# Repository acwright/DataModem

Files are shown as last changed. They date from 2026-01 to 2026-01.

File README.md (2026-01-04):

DataModem
=========

Data (RS-232/Serial) to Audio Modem

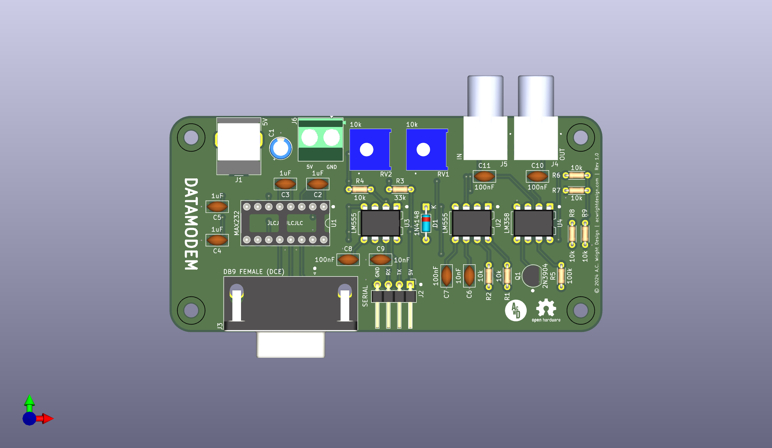
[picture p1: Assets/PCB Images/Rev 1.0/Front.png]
DataModem


Usage
-----

Connect the DataModem to your computer's serial port (or USB-to-Serial adapter) and to an audio input/output device (like a cassette recorder or audio interface). Use terminal software to send and receive data through the modem.

Configuration
--------------

- **Baud Rate**: 300 baud (recommended for best reliability)
- **Tone Frequency**: Approximately 4kHz
- **RV1**: Adjusts output signal strength to the cassette recorder
- **RV2**: Adjusts the triggering sensitivity of the Schmitt trigger for playback

How It Works
------------

The DataModem uses a simple one-tone encoding system where the presence of a tone represents a 1 bit and silence represents a 0 bit.

**Recording Data**: When transmitting, a 555 timer (U2) generates a ~4kHz square wave tone when the UART input is high. The tone is buffered and AC-coupled before being fed to the cassette recorder input. When the UART input is low, the 555 is disabled and produces no tone.

**Playing Back Data**: During playback, a Schmitt trigger detects the presence of the recorded tone. A retriggerable 555 monostable circuit (U3) converts the rapid tone pulses into a steady output signal. The monostable stays on for 300μs when triggered, and continuous triggers from the 4kHz tone keep it active, producing a clean digital output that matches the original UART signal.

The circuit is designed for 300 baud operation, providing excellent reliability with minimal bit loss when properly calibrated.

Licence
-------

This project is licensed under the CERN Open Hardware Licence Version 2 - Permissive License - see the [LICENSE](LICENSE) file for details.

Credits
-------

This project is inspired by and based on the following works:

- [Datacorder](https://www.mitchelectronics.co.uk/documents/DATACORD.pdf) by Mitchell Electronics
- [UART Cassette Tape Interface](https://maker.pro/pcb/projects/make-uart-cassette-tape-interface) by Robin Mitchell

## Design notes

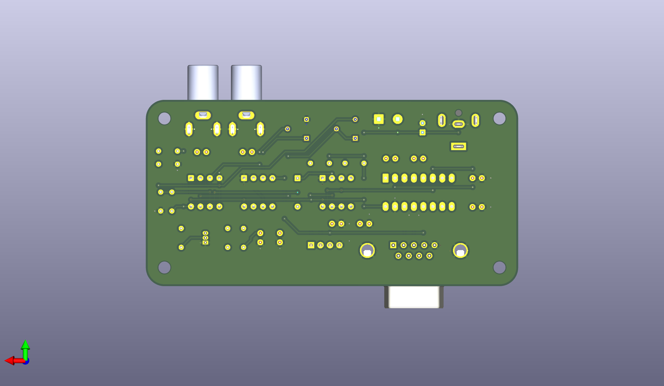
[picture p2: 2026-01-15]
Assets/PCB Images/Rev 1.0/Back.png

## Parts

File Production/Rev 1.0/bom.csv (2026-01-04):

Designator | Footprint | Quantity | Value | LCSC Part #
C1 | CP_Radial_D5.0mm_P2.50mm | 1 | 10uF
C10, C11, C7, C8 | C_Disc_D5.0mm_W2.5mm_P2.50mm | 4 | 100nF
C2, C3, C4, C5 | C_Disc_D5.0mm_W2.5mm_P2.50mm | 4 | 1uF | C28323
C6, C9 | C_Disc_D5.0mm_W2.5mm_P2.50mm | 2 | 10nF
D1 | D_DO-35_SOD27_P7.62mm_Horizontal | 1 | 1N4148
J1 | BarrelJack_CUI_PJ-063AH_Horizontal | 1 | 5V
J2 | PinHeader_1x04_P2.54mm_Horizontal | 1 | SERIAL
J4 | SWITCHCRAFT_PJRAN1X1U02X | 1 | OUT
J5 | SWITCHCRAFT_PJRAN1X1U02X | 1 | IN
J6 | TerminalBlock_Phoenix_MKDS-1,5-2-5.08_1x02_P5.08mm_Horizontal | 1 | 5V
Q1 | TO-92_Inline | 1 | 2N3904
R1, R2, R4, R6, R7, R8, R9 | R_Axial_DIN0204_L3.6mm_D1.6mm_P5.08mm_Horizontal | 7 | 10k
R3 | R_Axial_DIN0204_L3.6mm_D1.6mm_P5.08mm_Horizontal | 1 | 33k
R5 | R_Axial_DIN0204_L3.6mm_D1.6mm_P5.08mm_Horizontal | 1 | 100k
RV1, RV2 | 3386F-1-103LF | 2 | 10k
U1 | DIP-16_W7.62mm_Socket_LongPads | 1 | MAX232 | C59824
U2, U3 | DIP-8_W7.62mm | 2 | LM555
U4 | DIP-8_W7.62mm | 1 | LM358

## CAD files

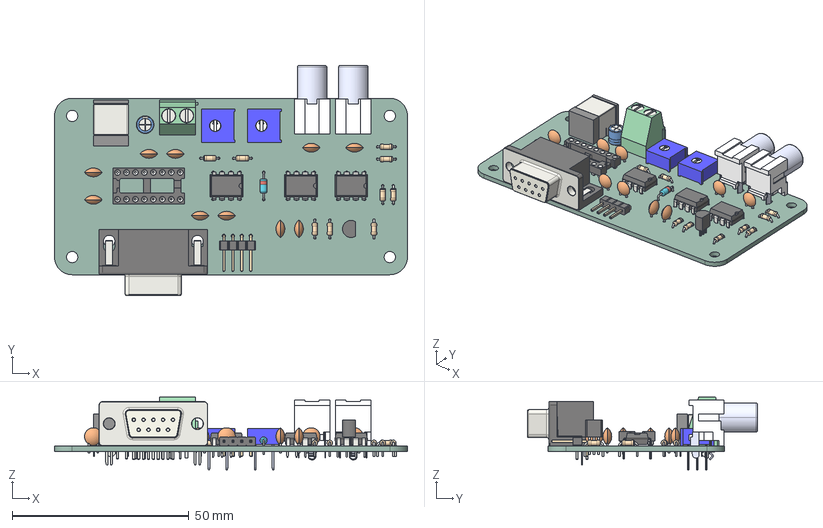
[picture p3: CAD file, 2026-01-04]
Assets/PCB Models/Rev 1.0/DataModem.step
100.0 x 65.3 x 20.7 mm
C_Disc_D5.0mm_W2.5mm_P2.50mm x 10
3386F-1-103LF x 2
DSUB-9_Socket_Horizontal_P2.77x2.84mm_EdgePinOffset7.70mm_Housed_ MountingHolesOffset9.12mm
CP_Radial_D5.0mm_P2.50mm
R_Axial_DIN0204_L3.6mm_D1.6mm_P5.08mm_Horizontal x 9
D_DO-35_SOD27_P7.62mm_Horizontal
TerminalBlock_Phoenix_MKDS-1,5-2-5.08_1x02_P5.08mm_Horizontal
BarrelJack_CUI_PJ-063AH_Horizontal
PJRAN1X1U04X-edit x 2
DIP-8_W7.62mm x 3
PinHeader_1x04_P2.54mm_Horizontal
TO-92_Inline
DIP-16_W7.62mm_Socket
DataModem_PCB

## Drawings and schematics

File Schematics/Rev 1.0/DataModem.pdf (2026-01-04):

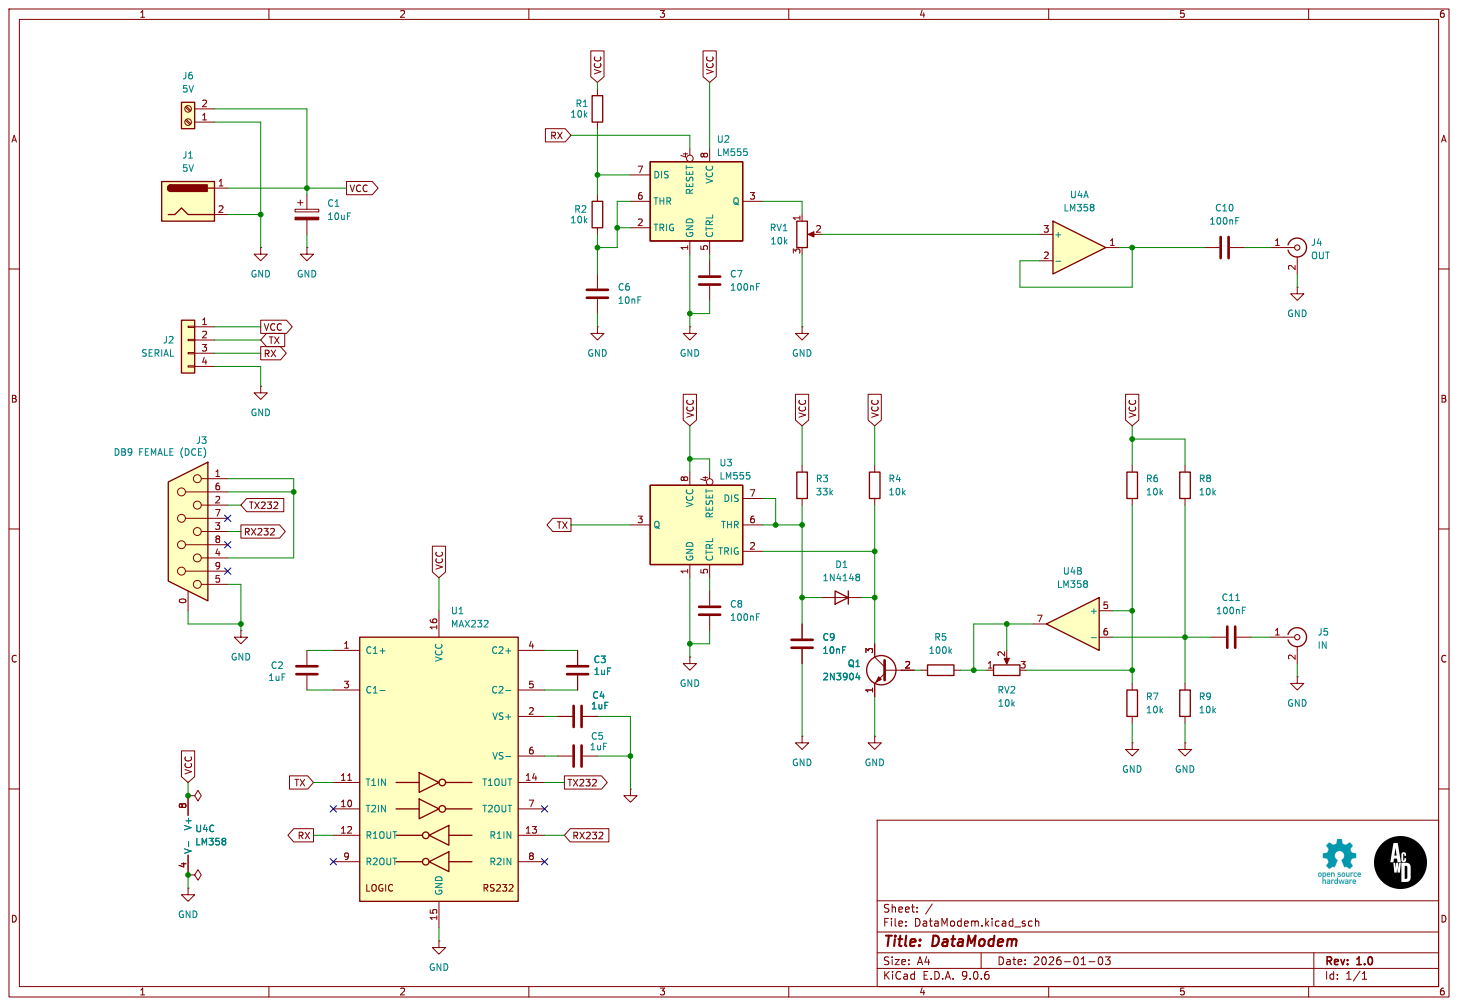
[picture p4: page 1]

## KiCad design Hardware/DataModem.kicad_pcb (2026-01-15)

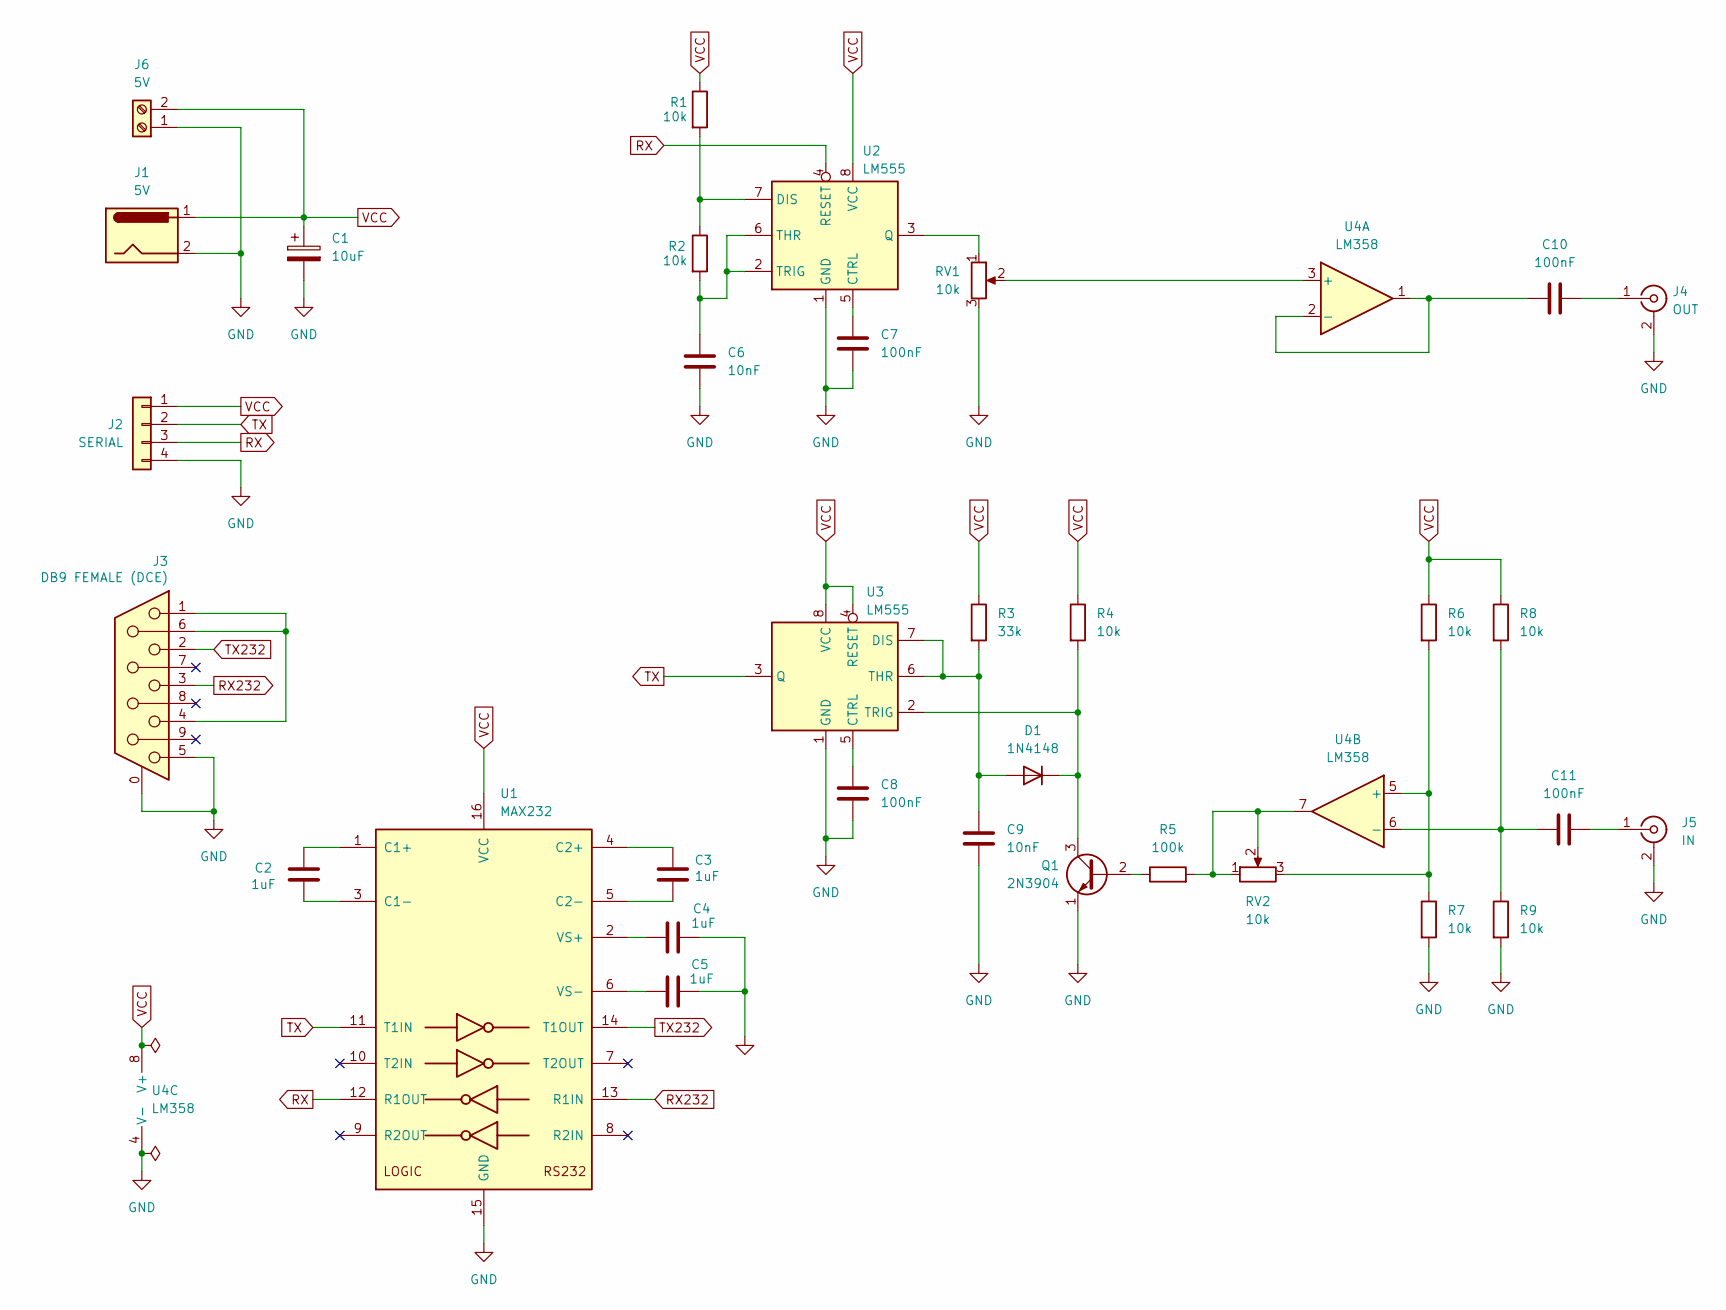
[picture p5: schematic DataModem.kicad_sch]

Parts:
C1: 10uF; CP_Radial_D5.0mm_P2.50mm
C2, C3, C4, C5: 1uF; C_Disc_D5.0mm_W2.5mm_P2.50mm; LCSC C28323
C6, C9: 10nF; C_Disc_D5.0mm_W2.5mm_P2.50mm
C7, C8, C10, C11: 100nF; C_Disc_D5.0mm_W2.5mm_P2.50mm
D1: 1N4148; D_DO-35_SOD27_P7.62mm_Horizontal
J1: 5V; BarrelJack_CUI_PJ-063AH_Horizontal
J2: SERIAL; PinHeader_1x04_P2.54mm_Horizontal
J3: DB9 FEMALE (DCE); DSUB-9_Socket_Horizontal_P2.77x2.84mm_EdgePinOffset7.70mm_H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; MPN D09S33E4GX00LF; Digikey 609-1487-ND
J4: OUT; SWITCHCRAFT_PJRAN1X1U02X
J5: IN; SWITCHCRAFT_PJRAN1X1U02X
J6: 5V; TerminalBlock_Phoenix_MKDS-1,5-2-5.08_1x02_P5.08mm_Horizont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
Q1: 2N3904; TO-92_Inline
R1, R2, R4, R6, R7, R8, R9: 10k; R_Axial_DIN0204_L3.6mm_D1.6mm_P5.08mm_Horizontal
R3: 33k; R_Axial_DIN0204_L3.6mm_D1.6mm_P5.08mm_Horizontal
R5: 100k; R_Axial_DIN0204_L3.6mm_D1.6mm_P5.08mm_Horizontal
RV1, RV2: 10k; 3386F-1-103LF
U1: MAX232; DIP-16_W7.62mm_Socket_LongPads; LCSC C59824
U2, U3: LM555; DIP-8_W7.62mm
U4: LM358; DIP-8_W7.62mm

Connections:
GND: C1.2, C4.2, C5.2, C6.2, C7.2, C8.2, C9.1, J1.2, J2.4, J3.0 (PAD), J3.5, J4.2 (Ext), J5.2 (Ext), J6.1, Q1.1 (E), R7.2, R9.2, RV1.3, U1.15 (GND), U2.1 (GND), U3.1 (GND), U4.4 (V-)
unnamed: C9.2, D1.2 (A), R3.2, U3.6 (THR), U3.7 (DIS)
unnamed: D1.1 (K), Q1.3 (C), R4.2, U3.2 (TRIG)
unnamed: J3.1, J3.4, J3.6
unnamed: C10.2, J4.1 (In)
unnamed: C11.1, J5.1 (In)
unnamed: Q1.2 (B), R5.1
unnamed: R5.2, RV2.1, RV2.2, U4.7
unnamed: C2.1, U1.1 (C1+)
unnamed: C2.2, U1.3 (C1-)
unnamed: C3.1, U1.4 (C2+)
unnamed: C3.2, U1.5 (C2-)
unnamed: C4.1, U1.2 (VS+)
unnamed: C5.1, U1.6 (VS-)
unnamed: C7.1, U2.5 (CTRL)
unnamed: R1.2, R2.1, U2.7 (DIS)
unnamed: RV1.1, U2.3 (Q)
unnamed: C6.1, R2.2, U2.2 (TRIG), U2.6 (THR)
unnamed: C8.1, U3.5 (CTRL)
unnamed: RV1.2, U4.3 (+)
unnamed: C10.1, U4.1, U4.2 (-)
unnamed: R6.2, R7.1, RV2.3, U4.5 (+)
unnamed: C11.2, R8.2, R9.1, U4.6 (-)
RX: J2.3, U1.12 (R1OUT), U2.4 (RESET)
RX232: J3.3, U1.13 (R1IN)
TX: J2.2, U1.11 (T1IN), U3.3 (Q)
TX232: J3.2, U1.14 (T1OUT)
VCC: C1.1, J1.1, J2.1, J6.2, R1.1, R3.1, R4.1, R6.1, R8.1, U1.16 (VCC), U2.8 (VCC), U3.4 (RESET), U3.8 (VCC), U4.8 (V+)

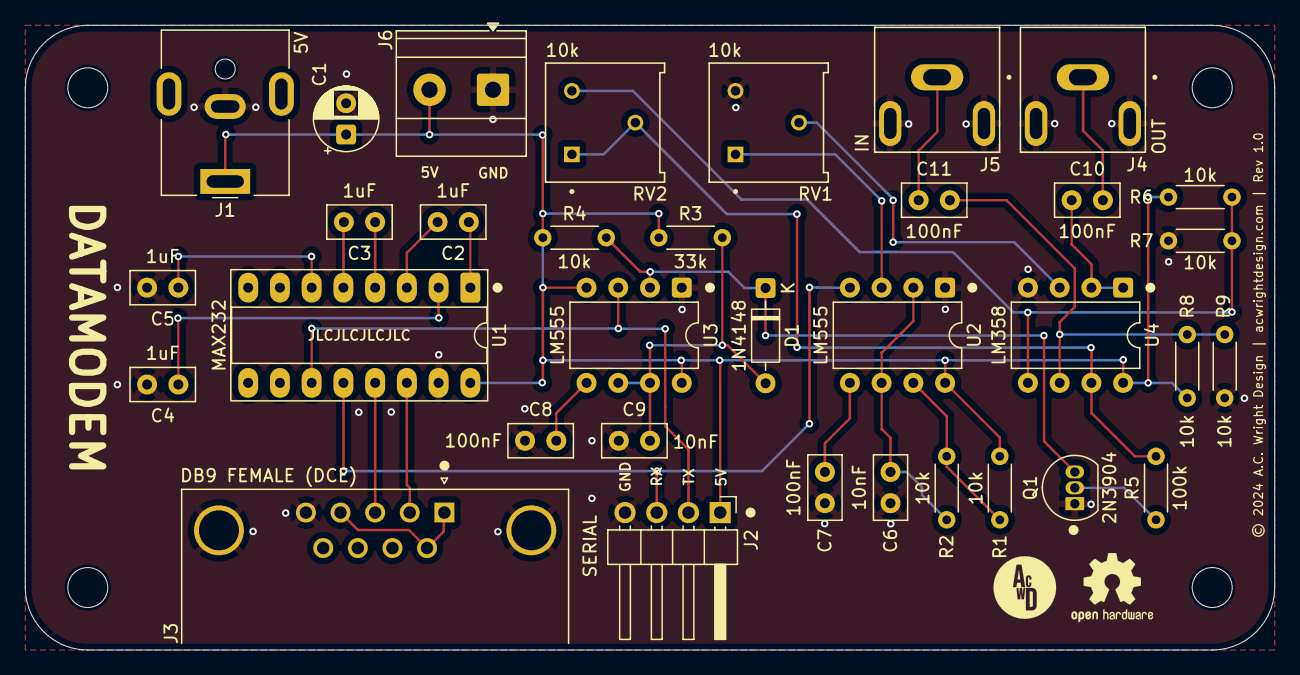
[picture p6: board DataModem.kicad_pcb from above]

Board: 2 copper layers, 100.0 x 50.0 mm, 34 parts (0 on the bottom side), 28 nets.

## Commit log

2026-01-04 Add PCB
    [DataModem.kicad_pcb, DataModem.kicad_sch, DataModem.step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]
2026-01-04 Add screw terminal for power input
    [DataModem.kicad_pcb, DataModem.kicad_sch, DataModem.step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]
2026-01-15 Production fixes
    [DataModem.kicad_pcb]

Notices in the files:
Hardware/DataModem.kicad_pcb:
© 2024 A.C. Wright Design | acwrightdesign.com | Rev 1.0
